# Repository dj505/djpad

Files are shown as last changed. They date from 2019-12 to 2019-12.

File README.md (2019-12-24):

# djPad
Open source, accessible, and hopefully inexpensive velostat based PIU pad design, for beginners and experts alike
---

<p align='center'>
 <b>Please consider supporting if you find this project helpful!</b><br>
  <a href='https://ko-fi.com/Y8Y8106HR' target='_blank'>Buy Me a Coffee at ko-fi.com</a>
</p>

# Features
- Wifi hotspot for web based sensitivity adjustment (code by [skogaby](https://github.com/skogaby), modified CSS by me)
- Lighting and IO support via custom PCB; Arduino Nano can output to any kind of input device, such as a PIUIO (or [PIUIO clone](https://github.com/racerxdl/piuio_clone/tree/simple/), keyboard, or controller via the digital pins (separate controller board required!)
- Doubles/2nd player pad support via custom PCB

# Parts List
- 2 x Arduino Nano (one per pad, only one required for singles)
- 1 x Wemos D1 Mini
- 1 x [All-in-one PCB](PCB/Gerber)
- 1 x Doubles/2nd player expansion board (only for doubles setup, coming soon!)
- JST XH connectors **(single pad)**
  - 6 x 2 pin JST XH right angle connectors
  - 3 x 6 pin JST XH right angle connectors
- JST XH connectors **(double pad)**
  - 11 x 2 pin JST XH right angle connectors
  - 6 x 6 pin JST XH right angle connectors

# Images

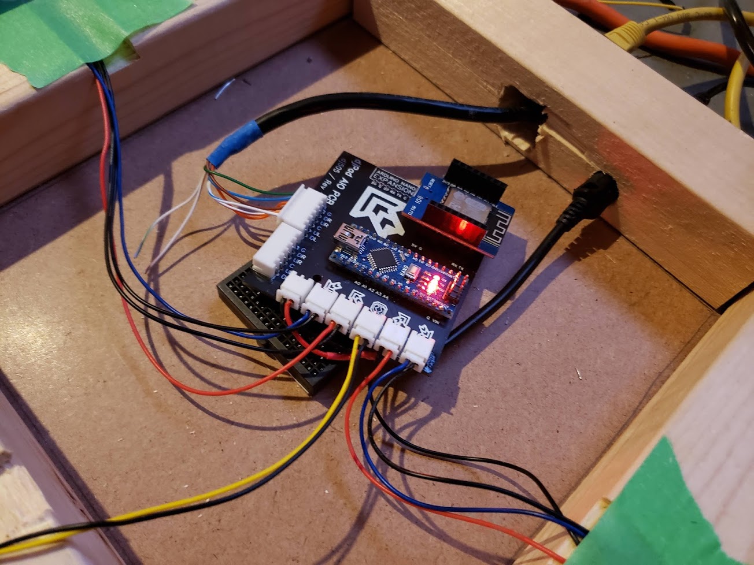
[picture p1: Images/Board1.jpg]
Board installed in pad

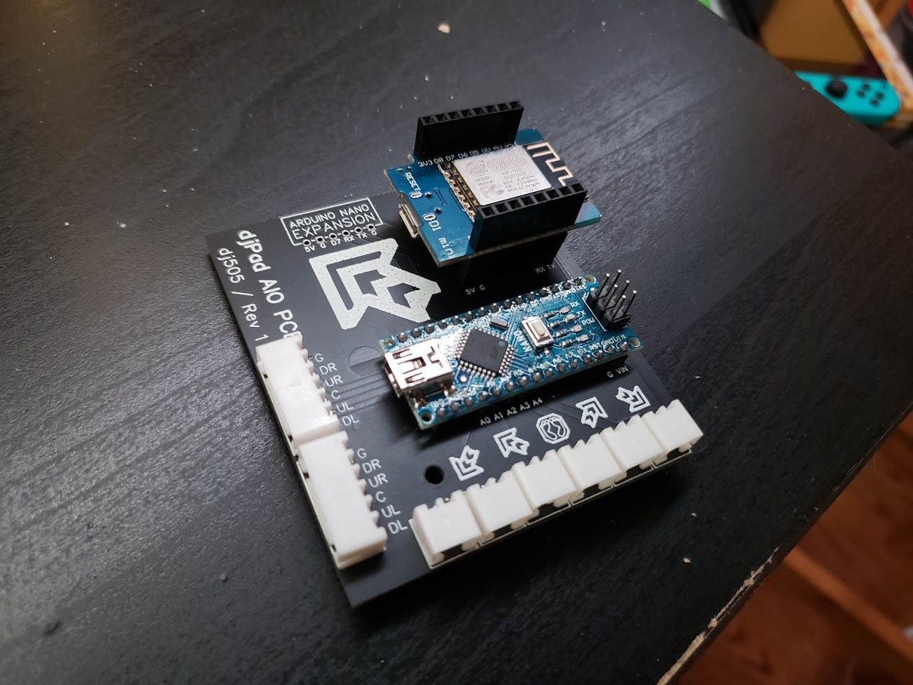
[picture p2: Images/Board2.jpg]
Board with components installed


# Credits
- Arduino/ESP8266 code - [Skogaby](https://github.com/skogaby/velostatdancecrew2k19/)
- cyberm4d, Xenesus, Astro, and [everyone else who's helped support the project!](https://ko-fi.com/dj505piu)

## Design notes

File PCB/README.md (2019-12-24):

# What are these?

These are files for the custom printed circuit board I designed to help make connecting the velostat and stuff easier! The PCB houses the Arduino Nano and Wemos D1 Mini, as well as the JST XH connectors for hooking up the sensors, power, lights, IO, and expansion stuff. 

# What is each file for?

The EasyEDA json file is for importing the project to EasyEDA. I designed this on the web-based version of the software, but I think it'll work with the desktop version too.

The Gerber zip is for uploading straight to a manufacturer to be ordered. I use JLCPCB since their services are super affordable, but I've also heard great things about OSH Park (they have some real neat purple PCBs as well).

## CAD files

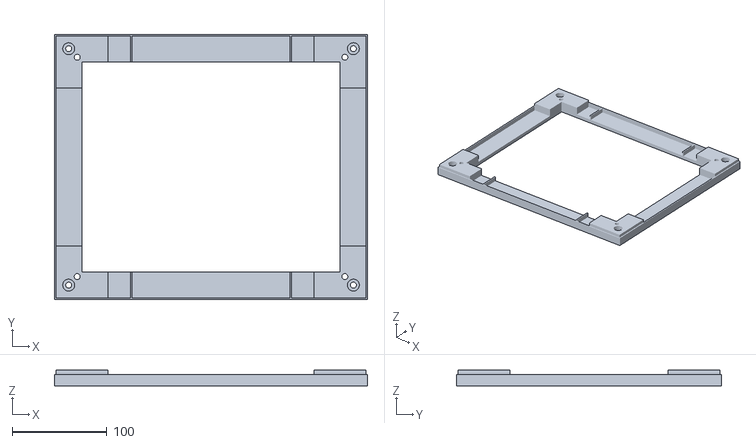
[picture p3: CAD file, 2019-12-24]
3D Printing/LR_Frame_AC_Accurate.stl
330.2 x 279.4 x 16.5

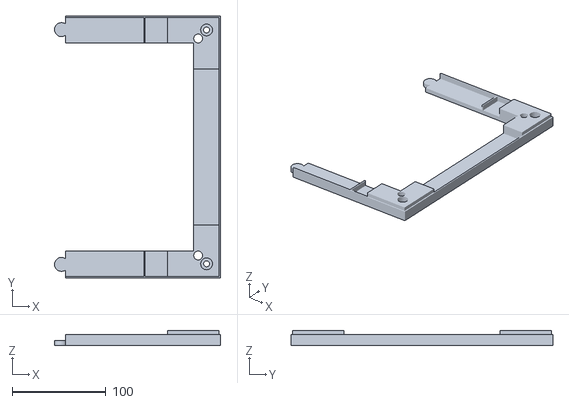
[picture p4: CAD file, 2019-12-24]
3D Printing/Split (for smaller printers)/LR_Frame_AC_Accurate_1.stl
177.1 x 279.4 x 16.5

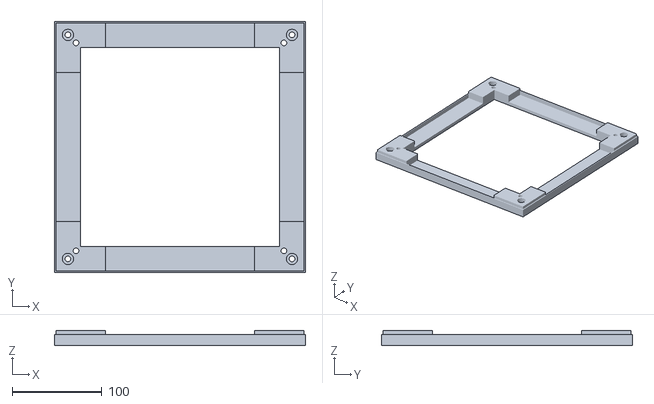
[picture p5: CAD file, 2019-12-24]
3D Printing/C_Frame_AC_Accurate.stl
279.4 x 279.4 x 16.5

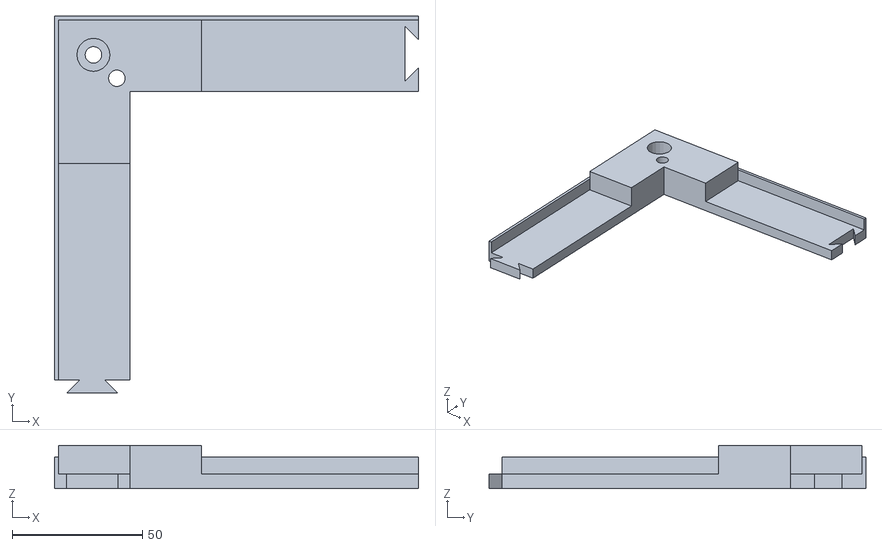
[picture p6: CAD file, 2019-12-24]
3D Printing/Split (for smaller printers)/C_Frame_AC_Accurate_Corner.stl
139.7 x 144.6 x 16.5

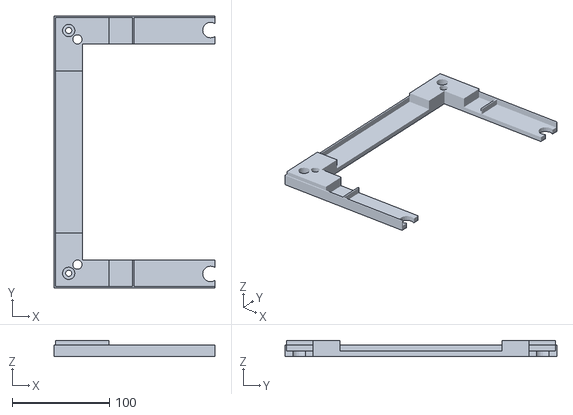
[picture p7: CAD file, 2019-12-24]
3D Printing/Split (for smaller printers)/LR_Frame_AC_Accurate_2.stl
165.1 x 279.4 x 16.5

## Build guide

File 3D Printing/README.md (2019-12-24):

# What are these parts?

The parts found here are 3D printable replicas of arcade accurate frames I designed to hold the sensors as well as secure the polycarbonate panels in place. 

The "Split" parts are split in either corners or halves, I haven't completed all of them yet, and you're free to split them yourself as well if needed. The parts outside that folder aren't split and are a single piece for printing on larger printers. My Creality CR-10S can print the entire C frame in one piece but can't print the LR frames without them being split in half, for example.

# Filenames

- Unsplit
  - C_Frame_AC_Accurate.stl - Center panel frame (also works for every individual arrow in a 4 panel pad)
  - LR_Frame_AC_Accurate.stl - Rectangular corner panel frames
- Split
  - C_Frame_AC_Accurate_Corner.stl - A single corner piece of the C frame, using a dovetail joint (May require sanding to fit)
  - LR_Frame_AC_Accurate_1.stl - Half of the rectangular LR frame, using an oval joint (May require sanding to fit)
  - LR_Frame_AC_Accurate_1.stl - Other half of the rectangular LR frame, using an oval joint (May require sanding to fit)

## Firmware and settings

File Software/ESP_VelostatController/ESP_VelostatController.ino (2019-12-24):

// uncomment if you want to run this on an ESP32
// not needed if you're using an ESP8266
// #include <EmbAJAXOutputDriverESPAsync.h>

#include <EEPROM.h>
#include <EmbAJAX.h>

#include "SensorAdjustmentPage.h"
#include "SerialUtils.h"

// constants for storing config values
#define CONFIG_VERSION "v0"
#define CONFIG_START 32
#define __5_PANEL__

// #################################################
// Wifi and webserver configuration
// #################################################

#ifdef __5_PANEL__
  #define WIFI_SSID "Pump It Up Pad - D1 Mini"
#else
  #define WIFI_SSID "Dance Dance Revolution Pad - TEST UNIT"
#endif

#define WIFI_PASSWORD "danceboiz2k19"

// setup web server and register it with EmbAJAX
EmbAJAXOutputDriverWebServerClass server(80);
EmbAJAXOutputDriver driver(&server);

// buffers to hold the strings to display on the page for our poll
// rates and sensor values
char p1pollBuf[8], p2pollBuf[8];
char p1a1buf[8], p1a2buf[8], p1a3buf[8], p1a4buf[8], p1a5buf[8], p2a1buf[8], p2a2buf[8], p2a3buf[8], p2a4buf[8], p2a5buf[8];
char p1a1thresh[8], p1a2thresh[8], p1a3thresh[8], p1a4thresh[8], p1a5thresh[8], p2a1thresh[8], p2a2thresh[8], p2a3thresh[8], p2a4thresh[8], p2a5thresh[8];
char* pollbufs[2] = { p1pollBuf, p2pollBuf };
char* displayBufs[2][5] = { { p1a1buf, p1a2buf, p1a3buf, p1a4buf, p1a5buf },
                          { p2a1buf, p2a2buf, p2a3buf, p2a4buf, p2a5buf } };
char* threshBufs[2][5] = { { p1a1thresh, p1a2thresh, p1a3thresh, p1a4thresh, p1a5thresh },
                          { p2a1thresh, p2a2thresh, p2a3thresh, p2a4thresh, p2a5thresh } };
EmbAJAXMutableSpan* pollrateDisplays[2] = { &p1pollrate, &p2pollrate };
EmbAJAXMutableSpan* valueDisplays[2][5] = { { &p1a1display, &p1a2display, &p1a3display, &p1a4display, &p1a5display },
                                         { &p2a1display, &p2a2display, &p2a3display, &p2a4display, &p2a5display } };
EmbAJAXTextInput<BUFLEN>* thresholdInputs[2][5] = { { &p1a1threshold, &p1a2threshold, &p1a3threshold, &p1a4threshold, &p1a5threshold },
                                         { &p2a1threshold, &p2a2threshold, &p2a3threshold, &p2a4threshold, &p2a5threshold } };

// ################################################
// Sensor and serial configuration 
// ################################################

#define SERIAL_ADDR_1 0x0A
#define SERIAL_ADDR_2 0x0B

uint16_t serialAddrs[2] = { SERIAL_ADDR_1, SERIAL_ADDR_2 };

#ifdef __5_PANEL__
  #define NUM_INPUTS 5
#else
  #define NUM_INPUTS 4
#endif

// the current thresholds for each arrow
struct THRESHOLD_DATA {
  uint16_t thresholds[NUM_INPUTS];
};

// the current values of each sensor, and the last poll rate
struct PAD_READOUT_DATA {
  uint16_t pressures[NUM_INPUTS];
  uint16_t pollRate;
};

THRESHOLD_DATA thresholdData[2];
PAD_READOUT_DATA padReadoutData[2];

// allow us to store threshold values in EEPROM
struct ConfigStore {
  char version[4];
  int thresholds[2][5];
} storage = {
  // defaults
  CONFIG_VERSION,
  { { 800, 800, 800, 800, 800 },
    { 800, 800, 800, 800, 800 } }
};

// timer so we can update the attached Arduinos
long lastMillis = 0;

// function prototypes
void initPage();
void handleUpdates();
void loadConfig();
void saveConfig();

/**
   Start the web server and setup comms with the slaves
*/
void setup() {
  // load the saved threshold values so we can send them to the arduinos
  loadConfig();

  // setup a wifi network to connect to this pad ad-hoc
  Serial.begin(115200);
  boolean result = WiFi.softAP(WIFI_SSID, WIFI_PASSWORD);
  
  if (result) {
    Serial.println("Wifi ready!");
    Serial.print("SSID: ");
    Serial.println(WIFI_SSID);
    Serial.print("Password: ");
    Serial.println(WIFI_PASSWORD);
  } else {
    Serial.println("Failed to setup the wifi!");
  }

  // setup the EmbAJAX content handlers and start the webserver
  driver.installPage(&page, "/", handleUpdates);
  server.begin();

  initPage();
}

/**
   Main program loop, keeps track of poll rate and updates the UI elements
   with current sensor values.
*/
void loop() {
  // keep track of our poll rate
  long currentMillis = millis();

  // every second, we need to send new sensitivities to the slaves
  if (currentMillis - lastMillis > 200) {
    for (int i = 0; i < 2; i++) {
      sendThresholds(i);
    }

    lastMillis = currentMillis;
  }

  // handle web clients
  driver.loopHook();

  // handle incoming serial data (pad readouts and poll rates)
  recvSerialBytes();
  checkSerialData();
}

/**
 * Send threshold data over serial with the specified player so we can address the packet
 */
void sendThresholds(int player) {
  Serial.println("Sending new thresholds to Arduino slaves");
  Serial.write(START_MARKER);

  uint16_t addr = (player == 0) ? SERIAL_ADDR_1 : SERIAL_ADDR_2;
  sendSerialInt(addr);

  for (int i = 0; i < NUM_INPUTS; i++) {
    sendSerialInt(thresholdData[player].thresholds[i]);
  }
  
  Serial.write(END_MARKER);
}

/**
 * Process incoming serial data from one of the Arduino slaves.
 */
void checkSerialData() {
  if (newData) {
    Serial.println("Receiving serial pad readout data");

    // check which address the message came from
    uint16_t addr = receivedBytes[0] | (receivedBytes[1] << 8);
    int player = (addr == SERIAL_ADDR_1) ? 0 : 1;

    // read the sensor readouts
    for (int i = 0; i < NUM_INPUTS; i++) {
      padReadoutData[player].pressures[i] = receivedBytes[(i * 2) + 2] | (receivedBytes[(i * 2) + 3] << 8);
    }

    // read the poll rate
    padReadoutData[player].pollRate = receivedBytes[(NUM_INPUTS * 2) + 2] | (receivedBytes[(NUM_INPUTS * 2) + 3] << 8);

    // update the UI elements with the new data
    for (int j = 0; j < NUM_INPUTS; j++) {
      (valueDisplays[player][j])->setValue(itoa(padReadoutData[player].pressures[j], displayBufs[player][j], 10));
    }
    
    pollrateDisplays[player]->setValue(itoa(padReadoutData[player].pollRate, pollbufs[player], 10));
    newData = false;
  }
}

/**
   Set the initial values for the page controls.
*/
void initPage() {
  for (int i = 0; i < 2; i++) {
    for (int j = 0; j < NUM_INPUTS; j++) {
      (thresholdInputs[i][j])->setValue(itoa(thresholdData[i].thresholds[j], threshBufs[i][j], 10));
    }
  }
}

/**
   Handle updates coming from the client, to change sensitivity thresholds.
*/
void handleUpdates() {
  bool shouldSave = false;

  for (int i = 0; i < 2; i ++) {
    for (int j = 0; j < NUM_INPUTS; j++) {
      int newValue = atoi((thresholdInputs[i][j])->value());
  
      // if the incoming value for this arrow is not what we had saved, then store
      // the value and update EEPROM
      if (thresholdData[i].thresholds[j] != newValue) {
        thresholdData[i].thresholds[j] = newValue;
        shouldSave = true;
      }
    }
  }

  if (shouldSave) {
    saveConfig();
  }
}

/**
   Loads the config values from EEPROM.
*/
void loadConfig() {
  EEPROM.begin(512);

  // If nothing is found it will use the default settings.
  if (EEPROM.read(CONFIG_START + 0) == CONFIG_VERSION[0] &&
      EEPROM.read(CONFIG_START + 1) == CONFIG_VERSION[1] &&
      EEPROM.read(CONFIG_START + 2) == CONFIG_VERSION[2]) {
    for (unsigned int t = 0; t < sizeof(storage); t++) {
      *((char*)&storage + t) = EEPROM.read(CONFIG_START + t);
    }
  }

  // update the thresholds with what we read from EEPROM
  for (int i = 0; i < 2; i++) {
    for (int j = 0; j < NUM_INPUTS; j++) {
      thresholdData[i].thresholds[j] = storage.thresholds[i][j];
    }
  }
}

/**
   Save the config values to EEPROM.
*/
void saveConfig() {
  // update the data we're going to store
  for (int i = 0; i < 2; i++) {
    for (int j = 0; j < NUM_INPUTS; j++) {
      storage.thresholds[i][j] = thresholdData[i].thresholds[j];
    }
  }

  // write the data
  for (unsigned int t = 0; t < sizeof(storage); t++) {
    EEPROM.write(CONFIG_START + t, *((char*)&storage + t));
  }

  EEPROM.commit();
}

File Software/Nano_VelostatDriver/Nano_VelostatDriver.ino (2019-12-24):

// uncomment this for 5-panel (PIU) mode
 #define __5_PANEL__ 
// uncomment this for player 2 mode
// #define __PLAYER_2__ 

#include "SerialUtils.h"

// these are the default sensitivity values we'll use, until
// overridden by the controller board
#define DEFAULT_SENSITIVITY 800

// set the serial address
#ifdef __PLAYER_2__
  #define SERIAL_ADDR 0x0B
#else
  #define SERIAL_ADDR 0x0A
#endif

// keep track of the current sensor values and what the thresholds
// are before we trigger a button press
#ifdef __5_PANEL__
  #define NUM_INPUTS 5
  int inputs[] = { A0, A1, A2, A3, A4 };
  int outputs[] = { 2, 3, 4, 5, 6 };
#else
  #define NUM_INPUTS 4
  int inputs[] = { A0, A1, A2, A3, A4 };
  int outputs[] = { 2, 3, 4, 5, 6 };
#endif


// the current thresholds for each arrow
struct THRESHOLD_DATA {
  uint16_t thresholds[NUM_INPUTS];
};

// the current values of each sensor, and the last poll rate
struct PAD_READOUT_DATA {
  uint16_t pressures[NUM_INPUTS];
  uint16_t pollRate;
};

THRESHOLD_DATA thresholdData;
PAD_READOUT_DATA padReadoutData;

// keep track of poll rate
long lastMillis = 0;
int loops = 0;

/**
 * Setup the IO pins
 */
void setup() {
  Serial.begin(115200);

  // init IO pins
  for (int i = 0; i < NUM_INPUTS; i++) {
    pinMode(inputs[i], INPUT_PULLUP);
    pinMode(inputs[i], HIGH);
    pinMode(outputs[i], OUTPUT);
    thresholdData.thresholds[i] = DEFAULT_SENSITIVITY;
  }
}

/**
 * Main program loop, drives the sensors and
 * updates the ESP32 SPI master
 */
void loop() {
  // keep track of our poll rate
  long currentMillis = millis();
  long deltaMillis = currentMillis - lastMillis;
  loops++;

  // every second, update the poll rate and send the readouts to the ESP module
  if (deltaMillis > 200) {
    padReadoutData.pollRate = (loops / (deltaMillis / 1000.0f));

    Serial.print("Current poll rate: ");
    Serial.print(padReadoutData.pollRate);
    Serial.println(" Hz");

    lastMillis = currentMillis;
    loops = 0;

    // update the ESP module
    sendReadouts();
  }

  // check if any of the buttons are pressed
  for (int i = 0; i < NUM_INPUTS; i++) {
    padReadoutData.pressures[i] = analogRead(inputs[i]);

    if (padReadoutData.pressures[i] <= thresholdData.thresholds[i]) {
      digitalWrite(outputs[i], LOW);
    } else {
      digitalWrite(outputs[i], HIGH);
    }
  }

  // check for updates from the ESP modules for new sensitivity thresholds and 
  // apply them if there are any
  recvSerialBytes();
  checkSerialData();
}

/**
 * Send the pad readouts and poll rate to the ESP module.
 */
void sendReadouts() {
    Serial.println("Sending pad readouts to ESP module");
    Serial.write(START_MARKER);

    sendSerialInt(SERIAL_ADDR);

    for (int i = 0; i < NUM_INPUTS; i++) {
      sendSerialInt(padReadoutData.pressures[i]);
    }

    sendSerialInt(padReadoutData.pollRate);
    Serial.write(END_MARKER);
}

/**
 * Receive new threshold values from the ESP module.
 */
void checkSerialData() {
  if (newData) {
    // make sure this message was for our address and not the other player's board
    uint16_t addr = receivedBytes[0] | (receivedBytes[1] << 8);

    // read the thresholds
    if (addr == SERIAL_ADDR) {
      for (int i = 0; i < NUM_INPUTS; i++) {
        thresholdData.thresholds[i] = receivedBytes[(i * 2) + 2] | (receivedBytes[(i * 2) + 3] << 8);
      }
      
      Serial.println("Reading threshold data from serial master");
      Serial.print("New thresholds: ");
      
      for (int i = 0; i < NUM_INPUTS; i++) {
        Serial.print(thresholdData.thresholds[i]);
        Serial.print(" ");
      }
      
      Serial.println("");
    }
    
    newData = false;
  }
 }

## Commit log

2019-12-24 Edited version of skogaby's Arduino/ESP8266 software
2019-12-24 Add PCB files
2019-12-24 Added 3D printable frames
    [C_Frame_AC_Accurate.stl, C_Frame_AC_Accurate_Corner.stl, LR_Frame_AC_Accurate.stl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]
